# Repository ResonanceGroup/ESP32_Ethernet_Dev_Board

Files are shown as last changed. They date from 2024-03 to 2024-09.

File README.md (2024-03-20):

This project is meant to test 2 different ethernet controller chips for the ESP32. The board is testing the W5100S and W5500. Only populate one or the other. Feel free to use this schematic as a reference. Or make your dev board that includes the ethernet controllers. If referencing off of the schematic, please provide credit to the original project (this one).

Will update later which circuit performed the best.

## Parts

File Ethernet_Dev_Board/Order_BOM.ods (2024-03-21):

Description | Mfg. | Mfg. PN | Distributor | Distributor PN | Qty Per Board | Total
CAP CER 10UF 16V X5R 0603 (https://www.digikey.com/en/products/detail/murata-electronics/GRM188R61C106MA73D/3900480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) | Murata Electronics | GRM188R61C106MA73D | Digikey | 490-7201-2-ND | 1 | 5 | Board Count | 5
CAP CER 22UF 10V X5R 0603 (https://www.digikey.com/en/products/detail/murata-electronics/GRM188R61A226ME15D/5027561) | Murata Electronics | GRM188R61A226ME15D | Digikey | 490-10476-1-ND | 6 | 30
CAP CER 0.1UF 25V X5R 0603 (https://www.digikey.com/en/products/detail/taiyo-yuden/tmk107bj104ka-t/930597) | Taiyo Yuden | TMK107BJ104KA-T | Digikey | 587-1245-2-ND | 28 | 140
CAP CER 2.2UF 10V X5R 0603 (https://www.digikey.com/en/products/detail/samsung-electro-mechanics/cl10a225kp8nnnc/3886743) | Samsung Electro-Mechanics | CL10A225KP8NNNC | Digikey | 1276-1085-2-ND | 3 | 15
CAP CER 1UF 10V X7R 0603 (https://www.digikey.com/en/products/detail/samsung-electro-mechanics/CL10B105KP8NFNC/3887603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) | Samsung Electro-Mechanics | CL10B105KP8NFNC | Digikey | 1276-1945-2-ND | 2 | 10
CAP CER 4.7UF 10V X5R 0603 (https://www.digikey.com/en/products/detail/samsung-electro-mechanics/CL10A475KP8NNNC/3886702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) | Samsung Electro-Mechanics | CL10A475KP8NNNC | Digikey | 1276-1044-2-ND | 1 | 5
CAP CER 10000PF 50V C0G/NP0 0603 (https://www.digikey.com/en/products/detail/murata-electronics/GRM1885C1H103JA01J/4905215) | Murata Electronics | GRM1885C1H103JA01J | Digikey | 490-GRM1885C1H103JA01JTR-ND | 1 | 5
CAP CER 6800PF 100V C0G 0603 (https://www.digikey.com/en/products/detail/tdk-corporation/c1608c0g2a682j080ac/5023339) | TDK Corporation | C1608C0G2A682J080AC | Digikey | 445-172661-2-ND | 2 | 10
CAP CER 1000PF 2KV X7R 1206 (https://www.digikey.com/en/products/detail/kyocera-avx/KGM31AR73D102MU/11207412) | KYOCERA AVX | KGM31AR73D102MU | Digikey | 478-KGM31AR73D102MUCT-ND | 2 | 10
CAP CER 18PF 50V C0G/NP0 0603 (https://www.digikey.com/en/products/detail/stackpole-electronics-inc/CML0603C0G180JT50V/10659983) | Stackpole Electronics Inc | CML0603C0G180JT50V | Digikey | 738-CML0603C0G180JT50VTR-ND | 4 | 20
DIODE GEN PURP 75V 150MA SOD523 (https://www.digikey.com/en/products/detail/micro-commercial-co/1n4148x-tp/789328) | Micro Commercial | 1N4148X-TP | Digikey | 1N4148XTPMSTR-ND | 2 | 10
FERRITE BEAD 30 OHM 0805 1LN (https://www.digikey.com/en/products/detail/bourns-inc/mh2029-300y/2563323) | Bourns Inc. | MH2029-300Y | Digikey | MH2029-300YTR-ND | 2 | 10
FERRITE BEAD 120 OHM 0603 1LN (https://www.digikey.com/en/products/detail/eaton-electronics-division/mfbm1v1608-121-r/13161218) | Eaton - Electronics Division | MFBM1V1608-121-R | Digikey | 283-MFBM1V1608-121-RTR-ND | 3 | 15
TERMINAL BLOCK, PLUGGABLE, 5.08, (https://www.digikey.com/en/products/detail/cui-devices/tbp01r1-508-02be/10238383) | CUI Devices | TBP01R1-508-02BE | Digikey | 102-6406-ND | 1 | 5
CONN JACK 1PORT 100 BASE-T PCB (https://www.digikey.com/en/products/detail/wiznet/RB1-125BAG1A/3829637?s=N4IgTCBcDaIIxgOwA4C0cAMc6oHIBEQBdAXyA) | WIZnet | RB1-125BAG1A | Digikey | 1278-1011-ND | 2 | 10
LED GREEN CLEAR 0805 SMD (https://www.digikey.com/en/products/detail/würth-elektronik/150080GS75000/4489915?s=N4IgTCBcDaIOwGYwFoAsBOAHA5KByAIiALoC%2BQA) | Wurth Electronics | 150080GS75000 | Digikey | 732-4983-2-ND | 1 | 5
LED RED CLEAR SMD (https://www.digikey.com/en/products/detail/liteon/LTST-C171KRKT/386801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) | Lite-On Inc. | LTST-C171KRKT | Digikey | 160-1427-2-ND | 2 | 10
LED BLUE CLEAR 0805 SMD (https://www.digikey.com/en/products/detail/inolux/IN-S85AT5B/7604912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) | Inolux | IN-S85AT5B | Digikey | 1830-1078-2-ND | 2 | 10
MOSFET P-CH 20V 4A TO236AB (https://www.digikey.com/en/products/detail/nexperia-usa-inc/PMV48XPA2R/11588668) | Nexperia USA Inc. | PMV48XPA2R | Digikey | 1727-PMV48XPA2RTR-ND | 1 | 5
RES 2.2K OHM 1% 1/10W 0603 (https://www.digikey.com/en/products/detail/stackpole-electronics-inc/RMCF0603FT2K20/1760987) | Stackpole Electronics Inc | RMCF0603FT2K20 | Digikey | RMCF0603FT2K20TR-ND | 1 | 5
RES 10K OHM 1% 1/10W 0603 (https://www.digikey.com/en/products/detail/stackpole-electronics-inc/RMCF0603FT10K0/1761235) | Stackpole Electronics Inc | RMCF0603FT10K0 | Digikey | RMCF0603FT10K0TR-ND | 8 | 40
RES ARRAY 8 RES 10K OHM 1206 (https://www.digikey.com/en/products/detail/yageo/YC158TJR-0710KL/5951826) | YAGEO | YC158TJR-0710KL | Digikey | 13-YC158TJR-0710KLTR-ND | 2 | 10
RES 470 OHM 1% 1/10W 0603 (https://www.digikey.com/en/products/detail/stackpole-electronics-inc/RMCF0603FT470R/1761144) | Stackpole Electronics Inc | RMCF0603FT470R | Digikey | RMCF0603FT470RTR-ND | 4 | 20
RES 12.4K OHM 1% 1/10W 0603 (https://www.digikey.com/en/products/detail/stackpole-electronics-inc/RMCF0603FT12K4/1761222) | Stackpole Electronics Inc | RMCF0603FT12K4 | Digikey | RMCF0603FT12K4TR-ND | 1 | 5
RES 49.9 OHM 1% 1/10W 0603 (https://www.digikey.com/en/products/detail/stackpole-electronics-inc/RMCF0603FT49R9/1760879) | Stackpole Electronics Inc | RMCF0603FT49R9 | Digikey | RMCF0603FT49R9TR-ND | 8 | 40
RES 10 OHM 1% 1/10W 0603 (https://www.digikey.com/en/products/detail/stackpole-electronics-inc/RMCF0603FT10R0/1761152) | Stackpole Electronics Inc | RMCF0603FT10R0 | Digikey | RMCF0603FT10R0TR-ND | 1 | 5
RES 1M OHM 1% 1/10W 0603 (https://www.digikey.com/en/products/detail/stackpole-electronics-inc/RMCF0603FG1M00/1713701) | Stackpole Electronics Inc | RMCF0603FG1M00 | Digikey | RMCF0603FG1M00TR-ND | 2 | 10
RES 3.3 OHM 5% 1/10W 0603 (https://www.digikey.com/en/products/detail/stackpole-electronics-inc/RMCF0603JT3R30/1712223) | Stackpole Electronics Inc | RMCF0603JT3R30 | Digikey | RMCF0603JT3R30TR-ND | 4 | 20
RES SMD 12.3KOHM 0.1% 1/10W 0603 (https://www.digikey.com/en/products/detail/yageo/RT0603BRD0712K3L/5927891) | YAGEO | RT0603BRD0712K3L | Digikey | 13-RT0603BRD0712K3LTR-ND | 1 | 5
RES 470K OHM 1% 1/10W 0603 (https://www.digikey.com/en/products/detail/stackpole-electronics-inc/RMCF0603FT470K/1761140) | Stackpole Electronics Inc | RMCF0603FT470K | Digikey | RMCF0603FT470KTR-ND | 1 | 5
SWITCH TACTILE SPST-NO 0.05A 12V (https://www.digikey.com/en/products/detail/cui-devices/TS04-66-43-BK-100-SMT/15634299) | CUI Devices | TS04-66-43-BK-100-SMT | Digikey | 2223-TS04-66-43-BK-100-SMT-ND | 2 | 10
TVS DIODE 3.3VWM 10.3VC DO214AA (https://www.digikey.com/en/products/detail/vishay-general-semiconductor-diodes-division/SMBJ3V3-E3-5B/2147834) | Vishay General Semiconductor - Diodes Division | SMBJ3V3-E3/5B | Digikey | SMBJ3V3-E3/5BGITR-ND | 1 | 5
IC REG LINEAR 3.3V 1A TO252-2 (https://www.digikey.com/en/products/detail/diodes-incorporated/AZ1117CD-3-3TRG1/4470979) | Diodes Incorporated | AZ1117CD-3.3TRG1 | Digikey | AZ1117CD-3.3TRG1DITR-ND | 1 | 5
IC GATE AND 1CH 2-INP 5TSSOP (https://www.digikey.com/en/products/detail/nexperia-usa-inc/74AUP1T08GWH/8276593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) | Nexperia USA Inc. | 74AUP1T08GWH | Digikey | 1727-7724-2-ND | 1 | 5
IC REG LINEAR 1.2V 150MA SOT23-5 (https://www.digikey.com/en/products/detail/texas-instruments/TLV74112PDBVR/7604405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) | Texas Instruments | TLV74112PDBVR | Digikey | 296-49998-2-ND | 1 | 5
IC CTLR 3-1 ETH TCP/IP 48LQFP (https://www.digikey.com/en/products/detail/wiznet/W5500/4425702) | WIZnet | W5500 | Digikey | 1278-W5500TR-ND | 1 | 5
IC ETHERNET CNTRLR SPI 48LQFP (https://www.digikey.com/en/products/detail/wiznet/W5100S-L/8789606) | Wiznet | W5100S-L | Digikey | 1278-W5100S-LTR-ND | 1 | 5
RF TXRX MODULE BT PCB TRACE SMD (https://www.digikey.com/en/products/detail/espressif-systems/ESP32-WROOM-32E-N8/13159522) | Expressif | ESP32-WROOM-32E-N8 | Digikey | 1965-ESP32-WROOM-32E-N8TR-ND | 1 | 5
IC GATE AND 1CH 3-INP SOT26 (https://www.digikey.com/en/products/detail/diodes-incorporated/74LVC1G11W6-7/3829446) | Diodes Incorporated | 74LVC1G11W6-7 | Digikey | 74LVC1G11W6-7TR-ND | 1 | 5
CRYSTAL 25.0MHZ 12PF SMD (https://www.digikey.com/en/products/detail/geyer-electronic-america-inc/12-60233/13980448) | Geyer Electronic America, Inc. | 12.60233 | Digikey | 4983-12.60233TR-ND | 2 | 10
XTAL OSC XO 25.0000MHZ CMOS SMD (https://www.digikey.com/en/products/detail/diodes-incorporated/FNETHE025/2273393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) | Diodes Incorporated | FNETHE025 | Digikey | FNETHE025TR-ND | 1 | 5
XTAL OSC XO 25MHZ 1.2V CMOS SMD (https://www.digikey.com/en/products/detail/taitien/OXLTDLJANF-25-000000/13235309) | Taitien | OXLTDLJANF-25.000000 | Digikey | 1664-OXLTDLJANF-25.000000TR-ND | 1 | 5

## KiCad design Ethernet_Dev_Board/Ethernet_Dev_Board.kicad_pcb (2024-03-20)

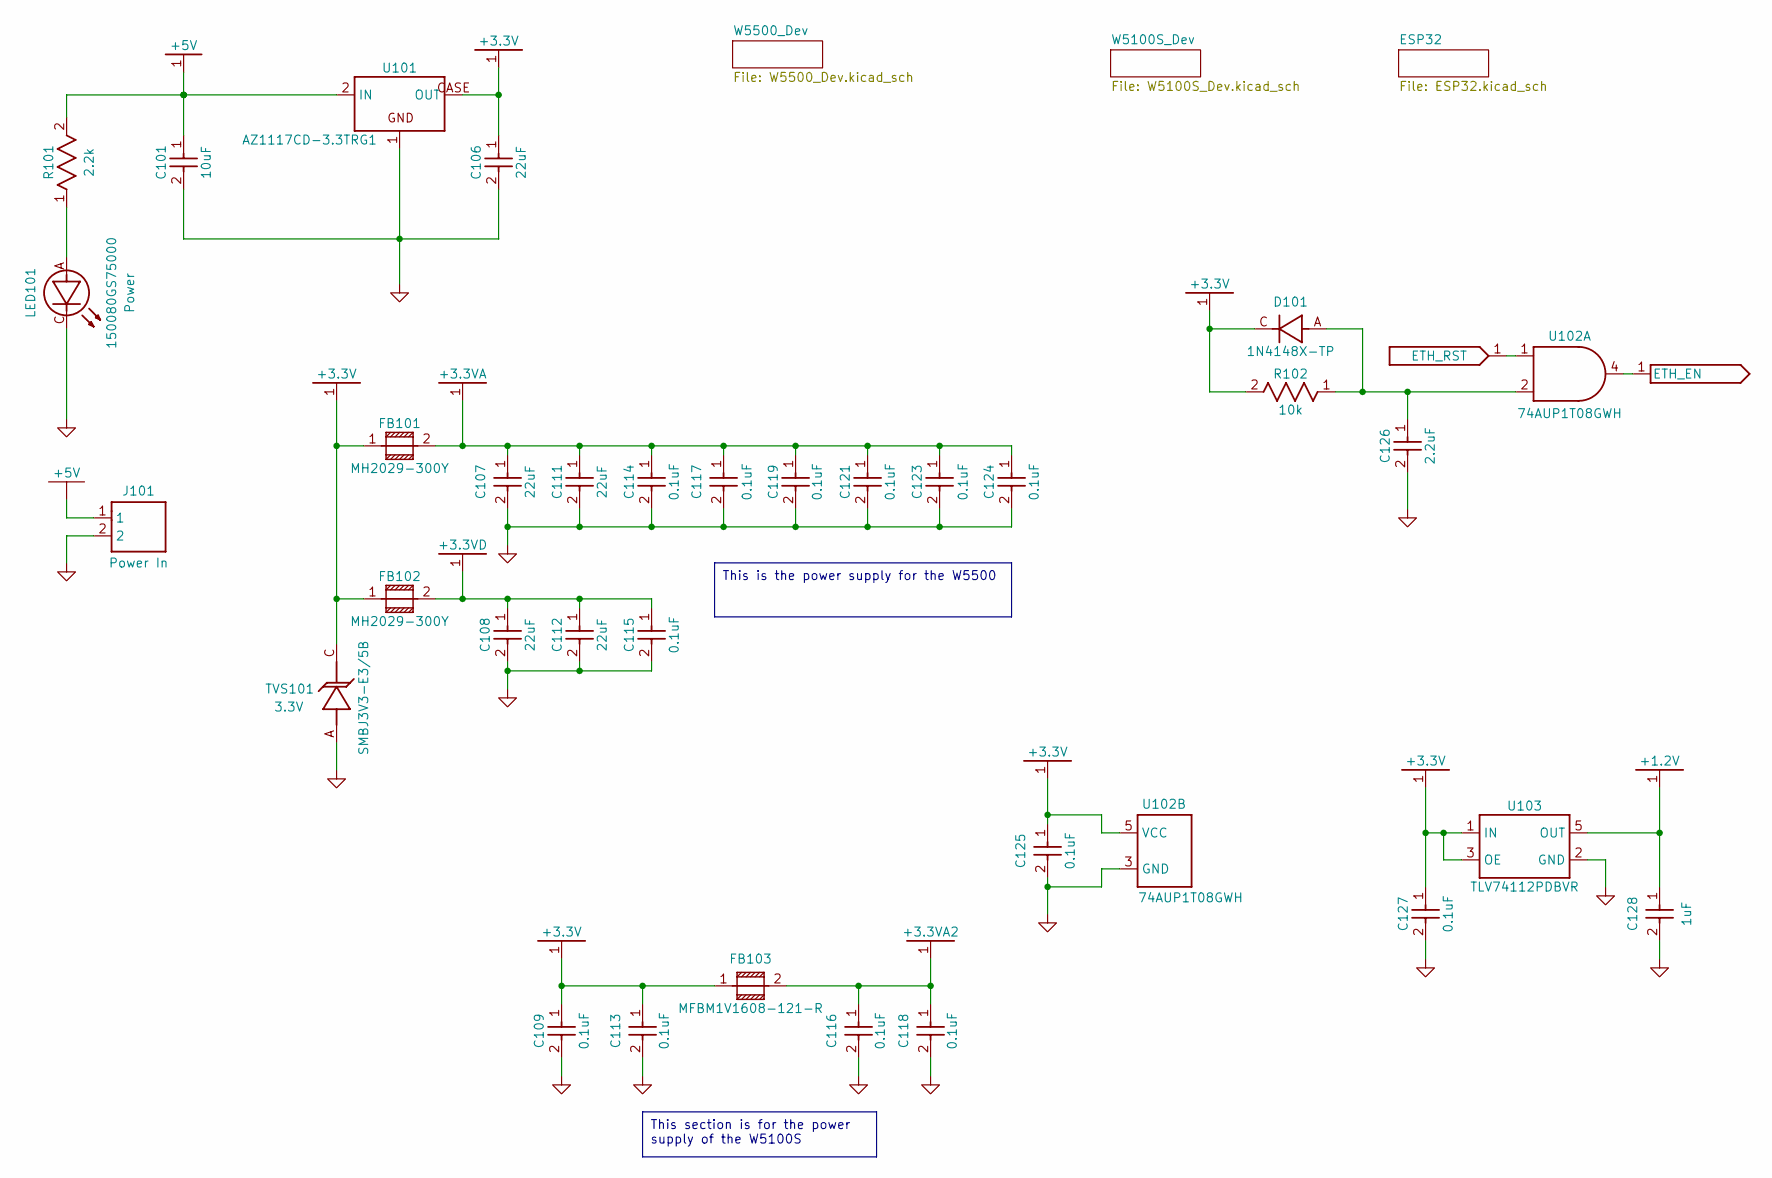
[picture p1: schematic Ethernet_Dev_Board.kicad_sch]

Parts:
C101: 10uF; 0603; Mfg. PN GRM188R61C106MA73D
C106, C107, C108, C111, C112: 22uF; 0603; Mfg. PN CL10A226MP8NUNE
C109, C113, C114, C115, C116, C117, C118, C119, C121, C123, C124, C125, C127: 0.1uF; 0603; Mfg. PN TMK107BJ104KA-T
C126: 2.2uF; 0603; Mfg. PN CL10A225KP8NNNC
C128: 1uF; 0603; Mfg. PN CL10B105KP8NFNC
D101: 1N4148X; SOD-523-D; Mfg. PN 1N4148X-TP
FB101, FB102: MH2029-300Y; 0805; Mfg. PN MH2029-300Y
FB103: 0603; Mfg. PN MFBM1V1608-121-R
J101: Power In; CUI_TBP01R1-508-02BE; Mfg. PN TBP01R1-508-02BE
LED101: Power; 0805-D; Mfg. PN 150080GS75000
R101: 2.2k; 0603; Mfg. PN RMCF0603FT2K20
R102: 10k; 0603; Mfg. PN RMCF0603FT10K0
TVS101: 3.3V; SMB-D; Mfg. PN SMBJ3V3-E3/5B
U101: AZ1117; TO252-3_(D-PAK); Mfg. PN AZ1117CD-3.3TRG1
U102: 74AUP1T08GWH; SOT23-5P65; Mfg. PN 74AUP1T08GWH
U103: 1.2V; SOT23-5P65; Mfg. PN TLV74112PDBVR

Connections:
+1.2V: C128.1, U103.5 (OUT); also elsewhere on the board
+3.3V: C106.1, C109.1, C113.1, C125.1, C127.1, D101.C, FB101.1, FB102.1, FB103.1, R102.2, TVS101.C (2), U101.CASE (OUT), U102.5 (VCC), U103.1 (IN), U103.3 (OE); also elsewhere on the board
+3.3VA: C107.1, C111.1, C114.1, C117.1, C119.1, C121.1, C123.1, C124.1, FB101.2; also elsewhere on the board
+3.3VA2: C116.1, C118.1, FB103.2; also elsewhere on the board
+3.3VD: C108.1, C112.1, C115.1, FB102.2; also elsewhere on the board
+5V: C101.1, J101.1, R101.2, U101.2 (IN); also elsewhere on the board
ETH_EN: U102.4 (Y); also elsewhere on the board
ETH_RST: U102.1 (A); also elsewhere on the board
GND1: C101.2, C106.2, C107.2, C108.2, C109.2, C111.2, C112.2, C113.2, C114.2, C115.2, C116.2, C117.2, C118.2, C119.2, C121.2, C123.2, C124.2, C125.2, C126.2, C127.2, C128.2, J101.2, LED101.C, TVS101.A (1), U101.1 (GND), U102.3 (GND), U103.2 (GND); also elsewhere on the board
unnamed: LED101.A, R101.1
unnamed: C126.1, D101.A, R102.1, U102.2 (C)

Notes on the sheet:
This is the power supply for the W5500
This section is for the power supply of the W5100S

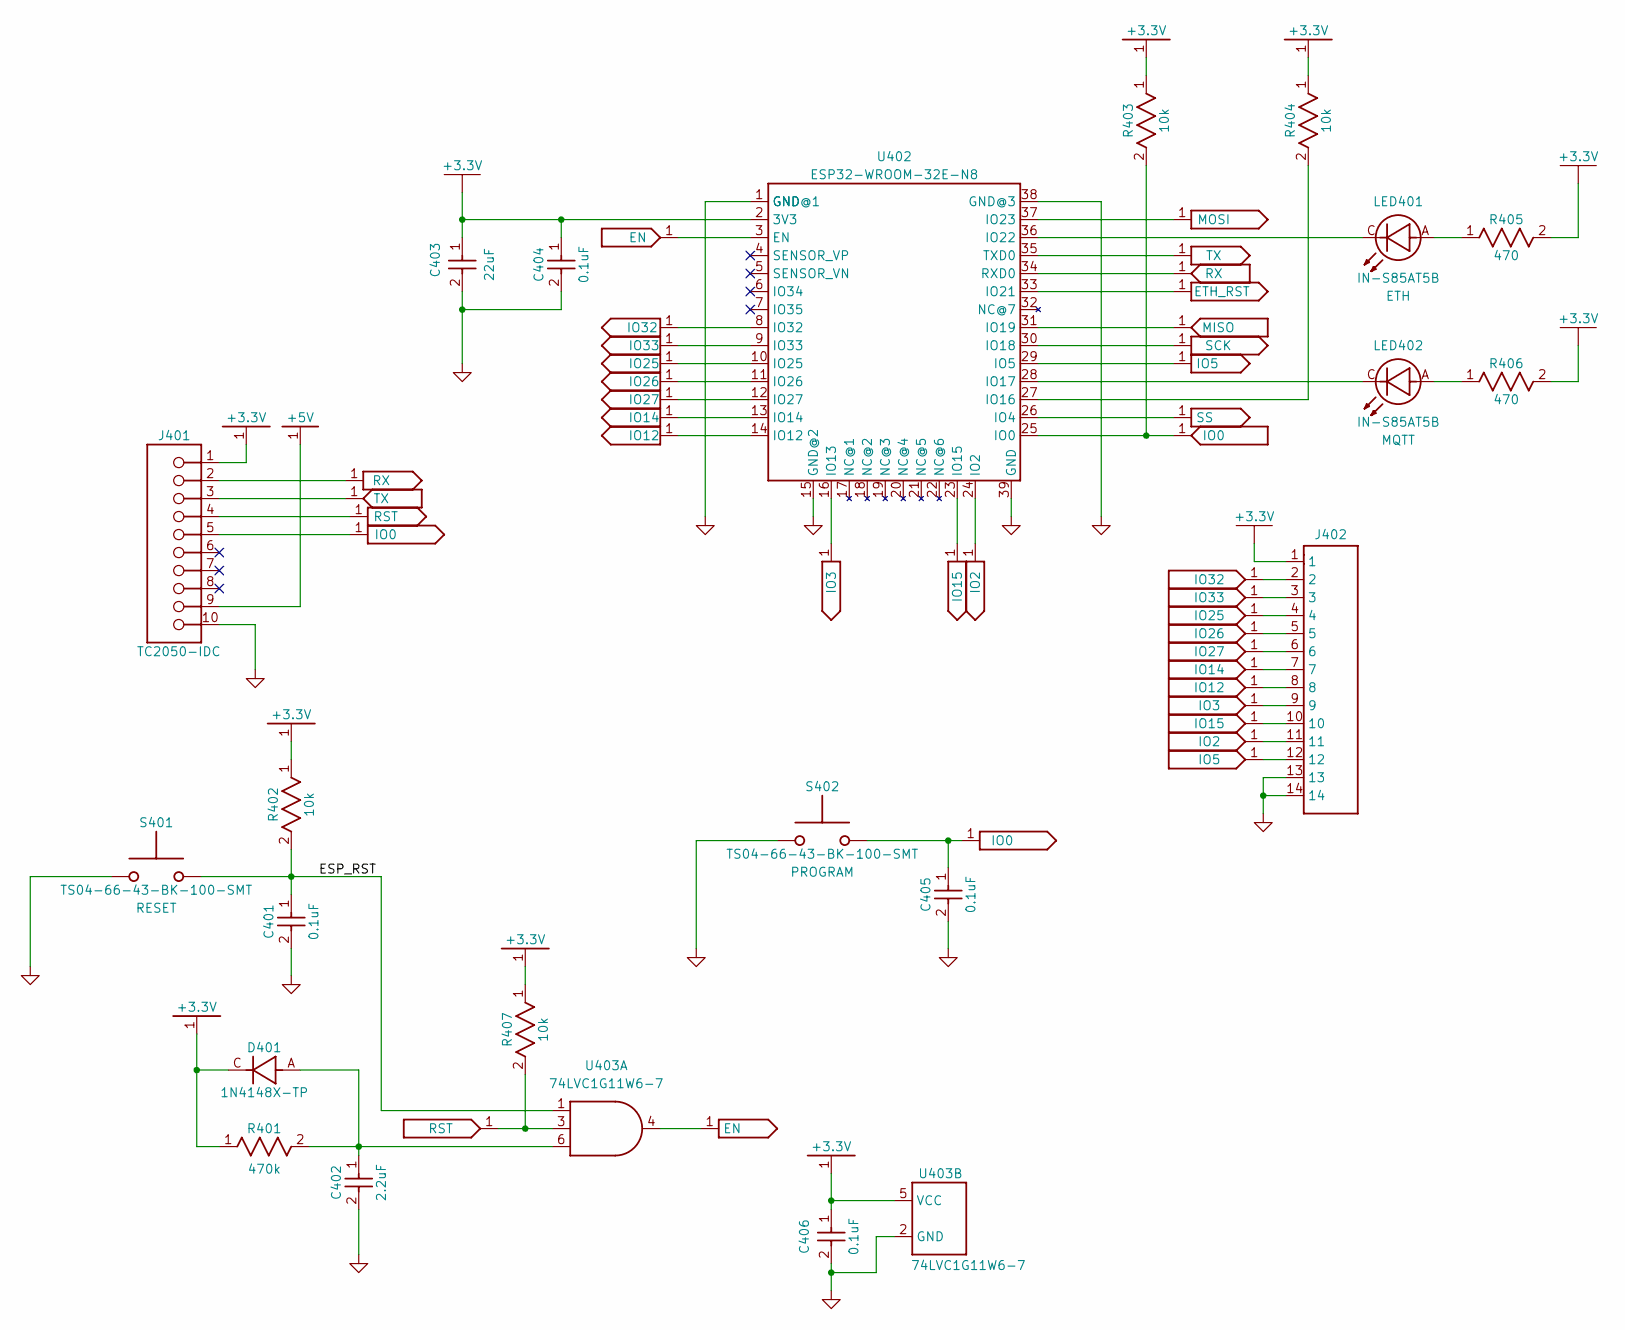
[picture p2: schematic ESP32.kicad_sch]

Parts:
C401, C404, C405, C406: 0.1uF; 0603; Mfg. PN TMK107BJ104KA-T
C402: 2.2uF; 0603; Mfg. PN CL10A225KP8NNNC
C403: 22uF; 0603; Mfg. PN CL10A226MP8NUNE
D401: 1N4148X; SOD-523-D; Mfg. PN 1N4148X-TP
J401: TAG-CONNECT_NL_10-POS_LEGS; TC2050-IDC; Mfg. PN TC2050-IDC
J402: PinHeader_1x14_P2.54mm_Vertical
LED401: ETH; 0805-D; Mfg. PN IN-S85AT5B
LED402: MQTT; 0805-D; Mfg. PN IN-S85AT5B
R401: 470k; 0603; Mfg. PN RMCF0603FT470K
R402, R403, R404, R407: 10k; 0603; Mfg. PN RMCF0603FT10K0
R405, R406: 470; 0603; Mfg. PN RMCF0603FT470R
S401: RESET; SW_TS04-66-65-BK-260-SMT; Mfg. PN TS04-66-43-BK-100-SMT
S402: PROGRAM; SW_TS04-66-65-BK-260-SMT; Mfg. PN TS04-66-43-BK-100-SMT
U402: ESP32-WROOM-32E; ESP32-WROOM_PCBANT; Mfg. PN ESP32-WROOM-32E-N8
U403: 74LVC1G11W6; SOT23-6; Mfg. PN 74LVC1G11W6-7

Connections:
+3.3V: C403.1, C404.1, C406.1, D401.C, J401.1, J402.1, R401.1, R402.1, R403.1, R404.1, R405.2, R406.2, R407.1, U402.2 (3V3), U403.5 (VCC); also elsewhere on the board
+5V: J401.9; also elsewhere on the board
/ESP32/ESP_RST: C401.1, R402.2, S401.1 (2), S401.3 (2), U403.1 (A)
EN: U402.3 (EN), U403.4 (Y)
ETH_RST: U402.33 (IO21); also elsewhere on the board
GND1: C401.2, C402.2, C403.2, C404.2, C405.2, C406.2, J401.10, J402.13, J402.14, S401.2 (1), S401.4 (1), S402.2 (1), S402.4 (1), U402.1 (GND), U402.15 (GND@2), U402.38 (GND@3), U402.39 (GND), U403.2 (GND); also elsewhere on the board
IO0: C405.1, J401.5, R403.2, S402.1 (2), S402.3 (2), U402.25 (IO0)
IO2: J402.11, U402.24 (IO2)
IO3: J402.9, U402.16 (IO13)
IO5: J402.12, U402.29 (IO5)
IO12: J402.8, U402.14 (IO12)
IO14: J402.7, U402.13 (IO14)
IO15: J402.10, U402.23 (IO15)
IO25: J402.4, U402.10 (IO25)
IO26: J402.5, U402.11 (IO26)
IO27: J402.6, U402.12 (IO27)
IO32: J402.2, U402.8 (IO32)
IO33: J402.3, U402.9 (IO33)
MISO: U402.31 (IO19); also elsewhere on the board
MOSI: U402.37 (IO23); also elsewhere on the board
unnamed: LED401.A, R405.1
unnamed: LED402.A, R406.1
unnamed: R404.2, U402.27 (IO16)
unnamed: LED402.C, U402.28 (IO17)
unnamed: LED401.C, U402.36 (IO22)
unnamed: C402.1, D401.A, R401.2, U403.6 (C)
RST: J401.4, R407.2, U403.3 (B)
RX: J401.2, U402.34 (RXD0)
SCK: U402.30 (IO18); also elsewhere on the board
SS: U402.26 (IO4); also elsewhere on the board
TX: J401.3, U402.35 (TXD0)

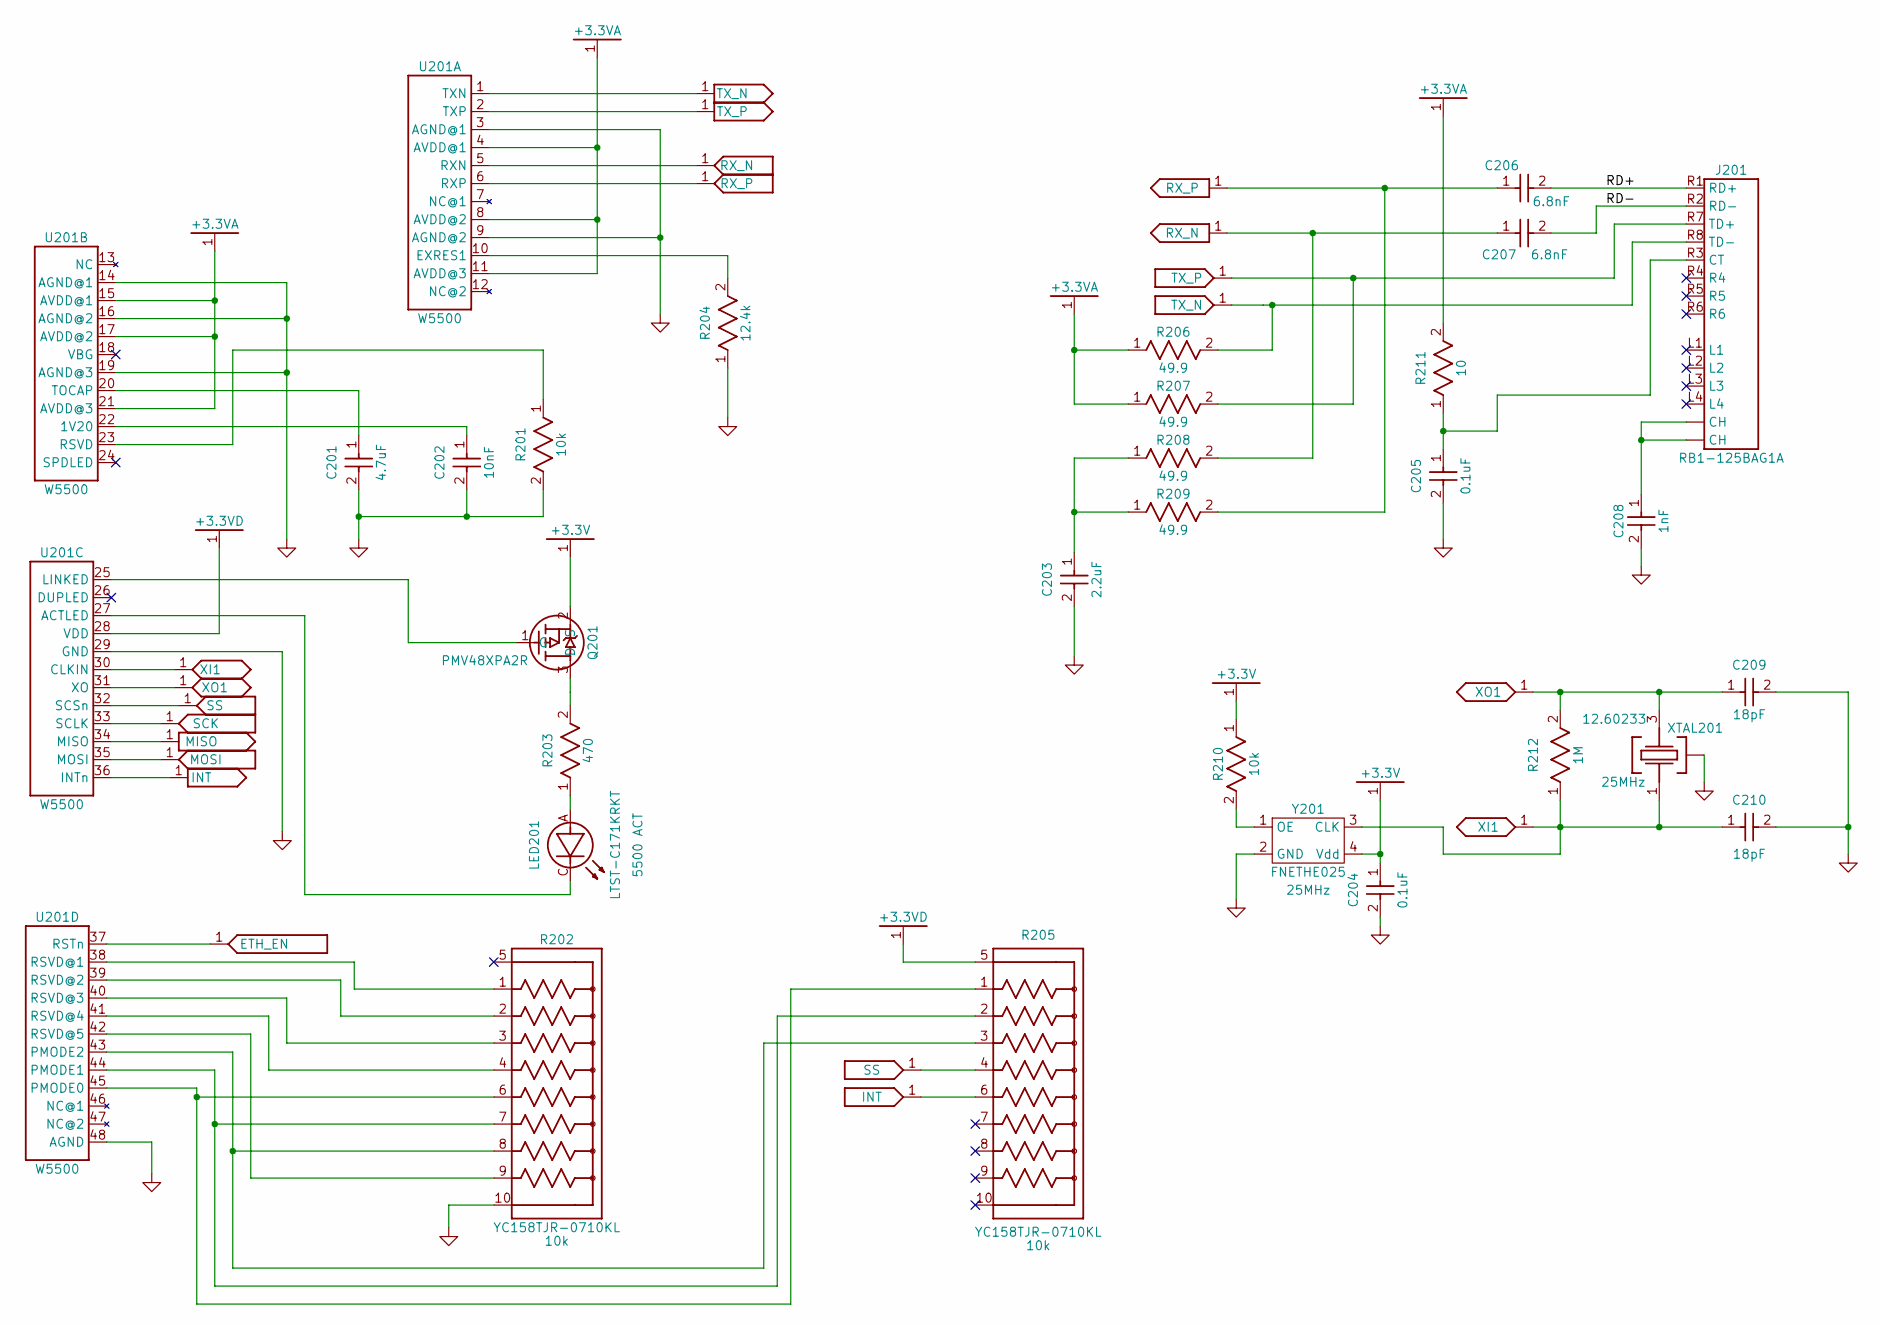
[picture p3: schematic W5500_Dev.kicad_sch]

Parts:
C201: 4.7uF; 0603; Mfg. PN CL10A475KP8NNNC
C202: 10nF; 0603; Mfg. PN GRM1885C1H103JA01J
C203: 2.2uF; 0603; Mfg. PN CL10A225KP8NNNC
C204, C205: 0.1uF; 0603; Mfg. PN TMK107BJ104KA-T
C206, C207: 6.8nF; 0603; Mfg. PN C1608C0G2A682J080AC
C208: 1nF; 1206; Mfg. PN C1206C102KGRAC7800
C209, C210: 18pF; 0603; Mfg. PN CML0603C0G180JT50V
J201: WIZNET_RB1-125BAG1A; Mfg. PN RB1-125BAG1A
LED201: 5500 ACT; 0805-D; Mfg. PN LTST-C171KRKT
Q201: PMV48XPA2R; SOT23-3P95; Mfg. PN PMV48XPA2R
R201, R210: 10k; 0603; Mfg. PN RMCF0603FT10K0
R202, R205: 10k; RESCAXS10P64_1206; Mfg. PN YC158TJR-0710KL
R203: 470; 0603; Mfg. PN RMCF0603FT470R
R204: 12.4k; 0603; Mfg. PN RMCF0603FT12K4
R206, R207, R208, R209: 49.9; 0603; Mfg. PN RMCF0603FT49R9
R211: 10; 0603; Mfg. PN RMCF0603FT10R0
R212: 1M; 0603; Mfg. PN RMCF0603FG1M00
U201: WIZNET_W5500; QFP48P50; Mfg. PN W5500
XTAL201: 25MHz; YANGXING_SMD_3225_4L; Mfg. PN 12.60233
Y201: 25MHz; Crystal_SMD_4Pin_7.0mmx5.0mm; Mfg. PN FNETHE025

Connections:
+3.3V: C204.1, Q201.2 (S), R210.1, Y201.4 (Vdd); also elsewhere on the board
+3.3VA: R206.1, R207.1, R211.2, U201.4 (AVDD@1), U201.8 (AVDD@2), U201.11 (AVDD@3), U201.15 (AVDD@1), U201.17 (AVDD@2), U201.21 (AVDD@3); also elsewhere on the board
+3.3VD: R205.5 (1@1), U201.28 (VDD); also elsewhere on the board
/W5500_Dev/RD+: C206.2, J201.R1 (RD+)
/W5500_Dev/RD-: C207.2, J201.R2 (RD-)
ETH_EN: U201.37 (RSTn); also elsewhere on the board
GND1: C201.2, C202.2, C203.2, C204.2, C205.2, C208.2, C209.2, C210.2, R201.2, R202.10 (1@2), R204.1, U201.3 (AGND@1), U201.9 (AGND@2), U201.14 (AGND@1), U201.16 (AGND@2), U201.19 (AGND@3), U201.29 (GND), U201.48 (AGND), XTAL201.2 (3@2), Y201.2 (GND); also elsewhere on the board
INT: R205.6, U201.36 (INTn)
MISO: U201.34 (MISO); also elsewhere on the board
MOSI: U201.35 (MOSI); also elsewhere on the board
unnamed: C203.1, R208.1, R209.1
unnamed: C208.1, J201.S1 (CH), J201.S2 (CH)
unnamed: C205.1, J201.R3 (CT), R211.1
unnamed: LED201.A, R203.1
unnamed: Q201.3 (D), R203.2
unnamed: Q201.1 (G), U201.25 (LINKED)
unnamed: R202.1 (2), U201.38 (RSVD@1)
unnamed: R202.2 (3), U201.39 (RSVD@2)
unnamed: R202.3 (4), U201.40 (RSVD@3)
unnamed: R202.4 (5), U201.41 (RSVD@4)
unnamed: R202.6, R205.1 (2), U201.45 (PMODE0)
unnamed: R202.7, R205.2 (3), U201.44 (PMODE1)
unnamed: R202.8, R205.3 (4), U201.43 (PMODE2)
unnamed: R204.2, U201.10 (EXRES1)
unnamed: C202.1, U201.22 (1V20)
unnamed: R201.1, U201.23 (RSVD)
unnamed: C201.1, U201.20 (TOCAP)
unnamed: LED201.C, U201.27 (ACTLED)
unnamed: R202.9, U201.42 (RSVD@5)
unnamed: R210.2, Y201.1 (OE)
RX_N: C207.1, R208.2, U201.5 (RXN)
RX_P: C206.1, R209.2, U201.6 (RXP)
SCK: U201.33 (SCLK); also elsewhere on the board
SS: R205.4 (5), U201.32 (SCSn); also elsewhere on the board
TX_N: J201.R8 (TD-), R206.2, U201.1 (TXN)
TX_P: J201.R7 (TD+), R207.2, U201.2 (TXP)
XI1: C210.1, R212.1, U201.30 (CLKIN), XTAL201.1, Y201.3 (CLK)
XO1: C209.1, R212.2, U201.31 (XO), XTAL201.3 (3@1)

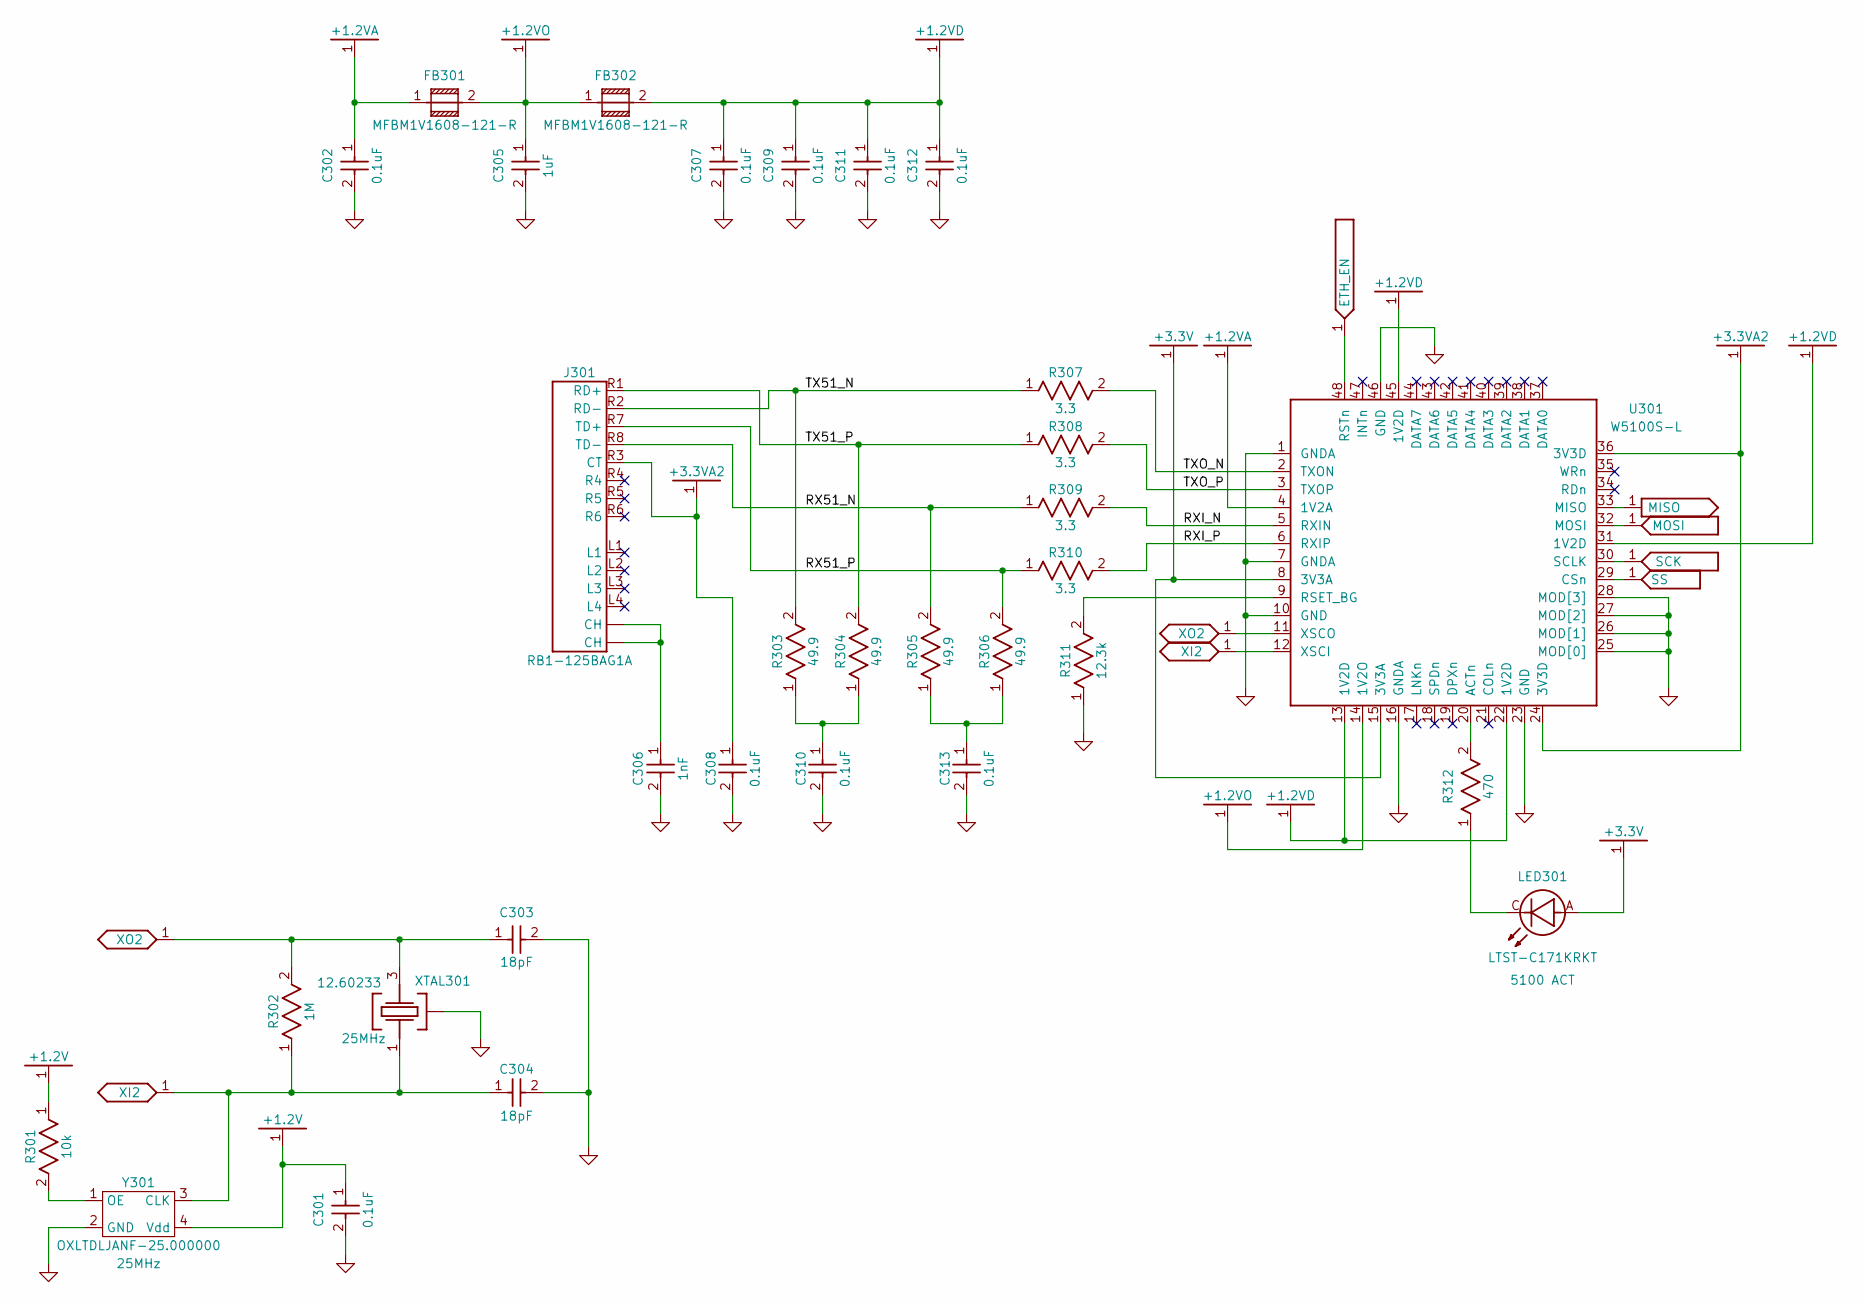
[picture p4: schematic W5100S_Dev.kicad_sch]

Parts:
C301, C302, C307, C308, C309, C310, C311, C312, C313: 0.1uF; 0603; Mfg. PN TMK107BJ104KA-T
C303, C304: 18pF; 0603; Mfg. PN CML0603C0G180JT50V
C305: 1uF; 0603; Mfg. PN CL10B105KP8NFNC
C306: 1nF; 1206; Mfg. PN C1206C102KGRAC7800
FB301, FB302: 0603; Mfg. PN MFBM1V1608-121-R
J301: WIZNET_RB1-125BAG1A; Mfg. PN RB1-125BAG1A
LED301: 5100 ACT; 0805-D; Mfg. PN LTST-C171KRKT
R301: 10k; 0603; Mfg. PN RMCF0603FT10K0
R302: 1M; 0603; Mfg. PN RMCF0603FG1M00
R303, R304, R305, R306: 49.9; 0603; Mfg. PN RMCF0603FT49R9
R307, R308, R309, R310: 3.3; 0603; Mfg. PN RMCF0603JT3R30
R311: 12.3k; 0603; Mfg. PN RT0603BRD0712K3L
R312: 470; 0603; Mfg. PN RMCF0603FT470R
U301: QFP48P50; Mfg. PN W5100S-L
XTAL301: 25MHz; YANGXING_SMD_3225_4L; Mfg. PN 12.60233
Y301: 25MHz; Crystal_SMD_4Pin_3.2x2.5mm; Mfg. PN OXLTDLJANF-25.000000

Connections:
+1.2V: C301.1, R301.1, Y301.4 (Vdd); also elsewhere on the board
+1.2VA: C302.1, FB301.1, U301.4 (1V2A)
+1.2VD: C307.1, C309.1, C311.1, C312.1, FB302.2, U301.13 (1V2D), U301.22 (1V2D), U301.31 (1V2D), U301.45 (1V2D)
+1.2VO: C305.1, FB301.2, FB302.1, U301.14 (1V2O)
+3.3V: LED301.A, U301.8 (3V3A), U301.15 (3V3A); also elsewhere on the board
+3.3VA2: C308.1, J301.R3 (CT), U301.24 (3V3D), U301.36 (3V3D); also elsewhere on the board
/W5100S_Dev/RX51_N: J301.R8 (TD-), R305.2, R309.1
/W5100S_Dev/RX51_P: J301.R7 (TD+), R306.2, R310.1
/W5100S_Dev/RXI_N: R309.2, U301.5 (RXIN)
/W5100S_Dev/RXI_P: R310.2, U301.6 (RXIP)
/W5100S_Dev/TX51_N: J301.R2 (RD-), R303.2, R307.1
/W5100S_Dev/TX51_P: J301.R1 (RD+), R304.2, R308.1
/W5100S_Dev/TXO_N: R307.2, U301.2 (TXON)
/W5100S_Dev/TXO_P: R308.2, U301.3 (TXOP)
ETH_EN: U301.48 (RSTn); also elsewhere on the board
GND1: C301.2, C302.2, C303.2, C304.2, C305.2, C306.2, C307.2, C308.2, C309.2, C310.2, C311.2, C312.2, C313.2, R311.1, U301.1 (GNDA), U301.7 (GNDA), U301.10 (GND), U301.16 (GNDA), U301.23 (GND), U301.25 (MOD[0]), U301.26 (MOD[1]), U301.27 (MOD[2]), U301.28 (MOD[3]), U301.46 (GND), XTAL301.2 (CASE), Y301.2 (GND); also elsewhere on the board
MISO: U301.33 (MISO); also elsewhere on the board
MOSI: U301.32 (MOSI); also elsewhere on the board
unnamed: C306.1, J301.S1 (CH), J301.S2 (CH)
unnamed: C310.1, R303.1, R304.1
unnamed: C313.1, R305.1, R306.1
unnamed: LED301.C, R312.1
unnamed: R312.2, U301.20 (ACTn)
unnamed: R311.2, U301.9 (RSET_BG)
unnamed: R301.2, Y301.1 (OE)
SCK: U301.30 (SCLK); also elsewhere on the board
SS: U301.29 (CSn); also elsewhere on the board
XI2: C304.1, R302.1, U301.12 (XSCI), XTAL301.1, Y301.3 (CLK)
XO2: C303.1, R302.2, U301.11 (XSCO), XTAL301.3 (3@1)

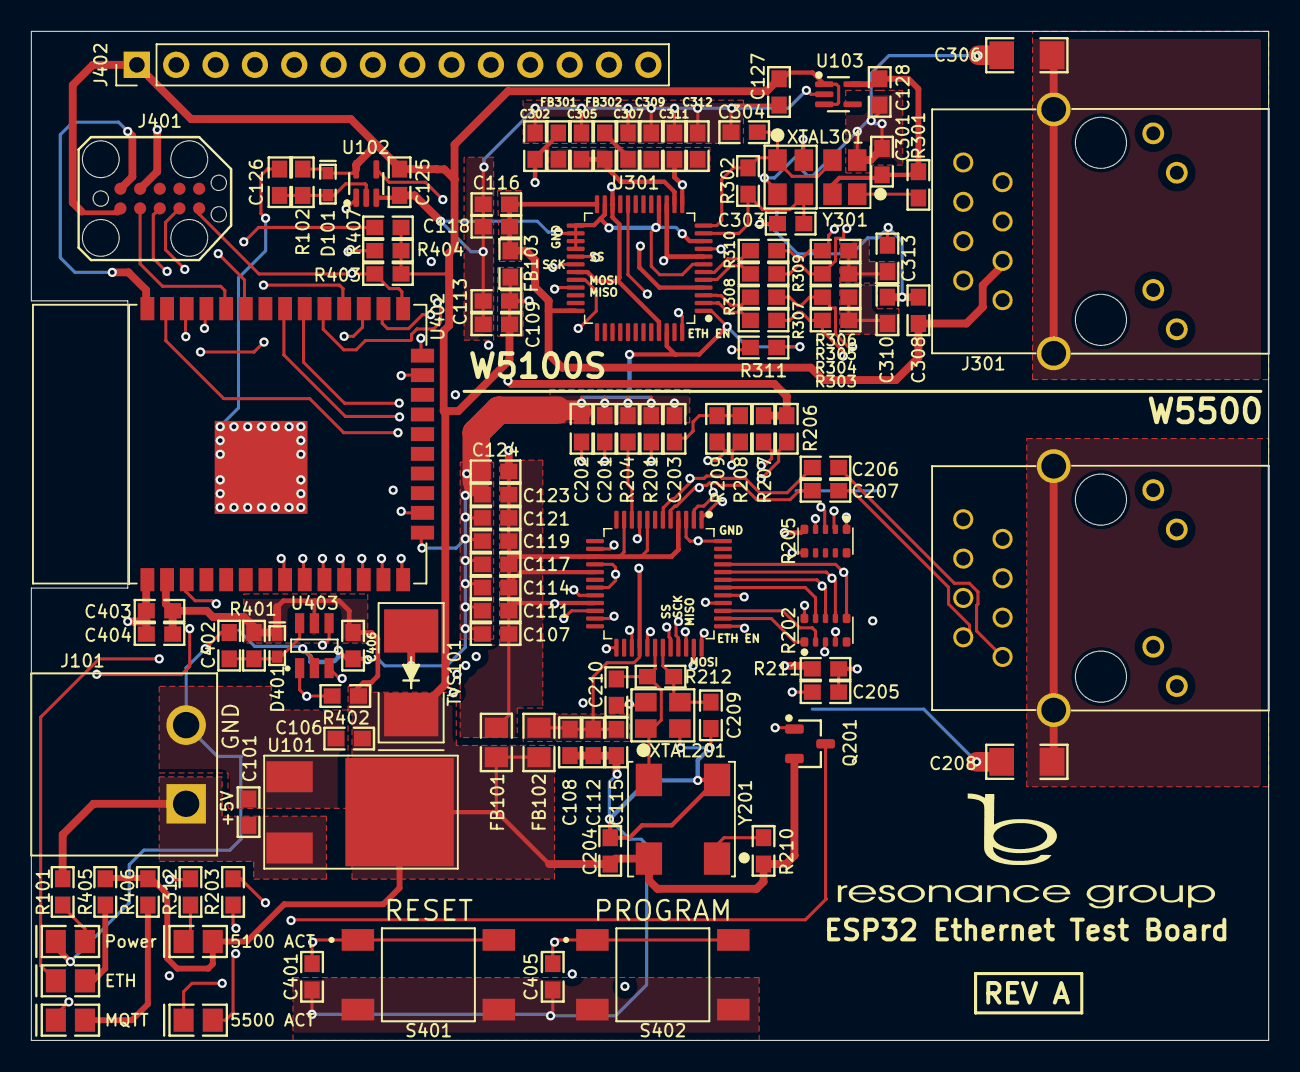
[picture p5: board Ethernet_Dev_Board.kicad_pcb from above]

Board: 4 copper layers, 79.9 x 65.2 mm, 115 parts (0 on the bottom side), 87 nets.

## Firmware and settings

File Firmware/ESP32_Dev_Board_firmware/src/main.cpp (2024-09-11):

#include <SPI.h>

#include <Arduino.h>
#include <PubSubClient.h>
#include "Ethernet.h"

#include <string.h>

#include <WiFi.h>

EthernetClient ethClient;
IPAddress serverIP(0,0,0,0);
void subscribeReceive(char* topic, byte* payload, unsigned int length); 
PubSubClient mqttClient(serverIP, 1883, subscribeReceive, ethClient);

String MQTTUserName = "User";
String MQTTPassword = "pass";

String deviceID;
String masterCommandString;
byte mac[] = { 0xA8, 0x61, 0x0A, 0xAF, 0x19, 0x30 };  

bool MQTTConnectionEstablished = false;
bool ethernetConnected = false;
bool payloadRecieved = false;

uint32_t mqttHeartbeatStartTime = 0;

unsigned long long macToID(String mac);
void connectMQTTServer();
void CheckEthernetComms();
void PrintMQTTLog(String message);

// Definitions
#define ETHERNET_RESET_PIN	21
#define SCLK_PIN  			18 
#define MISO_PIN  			19
#define MOSI_PIN  			23
#define SS_PIN    			8

#define ETH_LED		22
#define MQTT_LED	17

#define DHCP_TIMEOUT_VALUE_MS   30000
#define MAX_BUFFER_SIZE         256   

#define HEART_BEAT_TIMER_MS     60000


unsigned long long macToID(String mac)
{
    const char *originalMacString = mac.c_str();
    String newMacString = "";
    unsigned long long id = 0;

    for(int i = 0; i < mac.length(); i++){
        if(originalMacString[i] != ':'){
            newMacString.concat(originalMacString[i]);
        }
    }

    id = strtoull(newMacString.c_str(), NULL, 16);

    return id;
}

void setup() {
	Serial.begin(115200);
	deviceID = String(macToID(WiFi.macAddress()));

	Serial.println("New Program running");
	Serial.println(String("Device ID: ") + deviceID);

	pinMode(ETHERNET_RESET_PIN, OUTPUT);
	pinMode(ETH_LED, OUTPUT);
	pinMode(MQTT_LED, OUTPUT);
	pinMode(SS_PIN, OUTPUT);

	digitalWrite(ETH_LED, HIGH);
	digitalWrite(MQTT_LED, HIGH);

	digitalWrite(ETHERNET_RESET_PIN, HIGH);
	delay(500);

	Ethernet.init(SS_PIN);
	Serial.println("Turning on Ethernet");
	if(Ethernet.begin(mac, DHCP_TIMEOUT_VALUE_MS)){
		Serial.println("Ethernet running");
		ethernetConnected = true;
		digitalWrite(ETH_LED, LOW);
	} else {
		Serial.println("Ethernet failed to configure");
	}

	if(Ethernet.hardwareStatus() == EthernetW5500){
		Serial.println("Device is W5500");
	} else if(Ethernet.hardwareStatus() == EthernetW5100S){
		Serial.println("Device is W5100S");
	} else {
		Serial.println("Hardware communication issue");
	}

	Serial.println("Connecting MQTT Server");
	if(ethernetConnected){
		connectMQTTServer();
	}

	if(MQTTConnectionEstablished){
		Serial.println("Confirm MQTT Connected");
		PrintMQTTLog("Connected to server");
		digitalWrite(MQTT_LED, LOW);
	}

	Serial.println("Running loop function");
}

void loop() {
  	if(MQTTConnectionEstablished){
		mqttClient.loop();
	}

	if(millis() - mqttHeartbeatStartTime > HEART_BEAT_TIMER_MS){
		if(mqttClient.connected()){
			PrintMQTTLog(String("MQTT heartbeat: ") + String(millis() - mqttHeartbeatStartTime));
		}
		Serial.println(String("MQTT heartbeat: ") + String(millis() - mqttHeartbeatStartTime));
		mqttHeartbeatStartTime = millis();
	}

	if(ethernetConnected){
		Ethernet.maintain();
		CheckEthernetComms();
	}
}

void connectMQTTServer()
{
    Serial.println(F("Connecting to MQTT Server..."));

  //  mqttClient = PubSubClient(serverIP, 1883, subscribeReceive, ethClient);
    if(mqttClient.connect(deviceID.c_str(), MQTTUserName.c_str(), MQTTPassword.c_str())){
        Serial.println(F("Connection established"));
        mqttClient.subscribe(String(String("/device/") + deviceID + String("/command")).c_str());
        mqttClient.subscribe(String(String("/device/") + deviceID + String("/config")).c_str());
        mqttClient.subscribe(String(String("/device/") + deviceID + String("/update")).c_str());
        Serial.println(String("Link Established with version: ") + String("TEST DEV BOARD"));
        MQTTConnectionEstablished = true; // TODO: Test the logic for this being true in the main loop
    } else {
        Serial.println(Ethernet.linkStatus());
        Serial.println(String("Error while connecting: ") + String(mqttClient.state()));
        Serial.println(F("Connection not established"));
    }
}

void CheckEthernetComms()
{
	if (payloadRecieved){
		char commandCString[UDP_TX_PACKET_MAX_SIZE];
		memset(commandCString, 0, UDP_TX_PACKET_MAX_SIZE * sizeof(char));
		memcpy(commandCString, masterCommandString.c_str(), masterCommandString.length());

		// Only do the test command here
		if(!strcmp(commandCString, "test")){
			PrintMQTTLog("Test Command Recieved");
			Serial.println("Check MQTT Log");
		} else {
			Serial.println("Invalid command");
			PrintMQTTLog("Command not supported");
		}

        payloadRecieved = false;
    }
}

void subscribeReceive(char* topic, byte* payload, unsigned int length)
{
	payloadRecieved = true;
    String bufferString;
    String topicString = String(topic);

    for(int i = 0; i < length; i++){
        bufferString.concat((char)payload[i]);
    }

    Serial.println(String("Payload String: ") + bufferString);
    Serial.println(String(topic));
    
    masterCommandString = bufferString;
}

void PrintMQTTLog(String message) // TODO: Rename function
{
    mqttClient.publish(String(String("/server/") + deviceID + String("/log")).c_str(), message.c_str());
}

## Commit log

2024-03-13 Generated PCB file from schematic
    [ESP32.kicad_sch, Ethernet_Dev_Board.kicad_pcb, Ethernet_Dev_Board.kicad_sch]
2024-03-14 Added notes to schematics for changes
    [ESP32.kicad_sch, Ethernet_Dev_Board.kicad_sch]
2024-03-14 Associating footprint to component
    [Ethernet_Dev_Board.kicad_sch, W5500_Dev.kicad_sch]
2024-03-14 Added TVS diode and redid the LED circuit on the ESP32
    [ESP32.kicad_sch, Ethernet_Dev_Board.kicad_sch, W5100S_Dev.kicad_sch]
2024-03-14 Updated notes in schematic
    [ESP32.kicad_sch, W5100S_Dev.kicad_sch]
2024-03-14 Added in 1.2 V regulator and broke out unused IO pins to header
    [ESP32.kicad_sch, Ethernet_Dev_Board.kicad_pcb, Ethernet_Dev_Board.kicad_sch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]
2024-03-14 Net adjustments. Beginning board layout
    [ESP32.kicad_sch, Ethernet_Dev_Board.kicad_pcb, Ethernet_Dev_Board.kicad_sch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]
2024-03-15 Initial component placement
    [Ethernet_Dev_Board.kicad_pcb]
2024-03-15 Removed 1 TVS diode. removed 1 reset circuit. Placed Ethernet port in both W5500 and W5100S circuits
    [ESP32.kicad_sch, Ethernet_Dev_Board.kicad_pcb, Ethernet_Dev_Board.kicad_sch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]
2024-03-16 Removed unnecessary nets. Beginning board routing
    [ESP32.kicad_sch, Ethernet_Dev_Board.kicad_pcb, Ethernet_Dev_Board.kicad_sch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]
2024-03-16 Finished first version of routing the board. Also adjusted some nets
    [Ethernet_Dev_Board.kicad_pcb, W5100S_Dev.kicad_sch, W5500_Dev.kicad_sch]
2024-03-18 Minor updates
    [Ethernet_Dev_Board.kicad_pcb]
2024-03-18 Converted Board into 4 layers
    [Ethernet_Dev_Board.kicad_pcb, W5100S_Dev.kicad_sch]
2024-03-18 Fixed DRC errors. Edited layout stack
    [Ethernet_Dev_Board.kicad_pcb]
2024-03-18 Rev A Design files finish
    [ESP32.kicad_sch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]
2024-03-18 Added ordering BOM for REV A
    [ESP32.kicad_sch, Ethernet_Dev_Board.kicad_sch, Order_BOM.ods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]
2024-03-19 Added RG logo
    [Ethernet_Dev_Board.kicad_pcb]
2024-03-19 Adjusted RG logo
    [Ethernet_Dev_Board.kicad_pcb]
2024-03-19 Small adjustment
    [ESP32.kicad_sch]
2024-03-19 Created Updated gerber files
    [Ethernet_Dev_Board-B_Cu.gbr, Ethernet_Dev_Board-B_Mask.gbr, Ethernet_Dev_Board-Edge_Cuts.gbr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]
2024-03-20 Fixed an issue with a footprint that had height and width of 0,0
    [Ethernet_Dev_Board-B_Cu.gbr, Ethernet_Dev_Board-B_Mask.gbr, Ethernet_Dev_Board-Edge_Cuts.gbr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]
2024-03-20 Last update before sending out to fabrication
    [Ethernet_Dev_Board-B_Cu.gbr, Ethernet_Dev_Board-B_Mask.gbr, Ethernet_Dev_Board-Edge_Cuts.gbr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]
2024-03-21 Updated part(s) due to out of stock
    [ESP32.kicad_sch, Ethernet_Dev_Board.kicad_sch, Order_BOM.ods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]
2024-03-28 Added in firmware needed to run the test board
2024-09-11 Changed cap value to 2.2 and changed SS pin
    [Ethernet_Dev_Board.kicad_sch]
